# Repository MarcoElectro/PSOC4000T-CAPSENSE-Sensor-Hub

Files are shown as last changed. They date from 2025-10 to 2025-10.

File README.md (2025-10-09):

# PSOC4000T-CAPSENSE-Sensor-Hub
An simple way to use capacitive sensors in combination with Infineon's CAPSENSE technology.

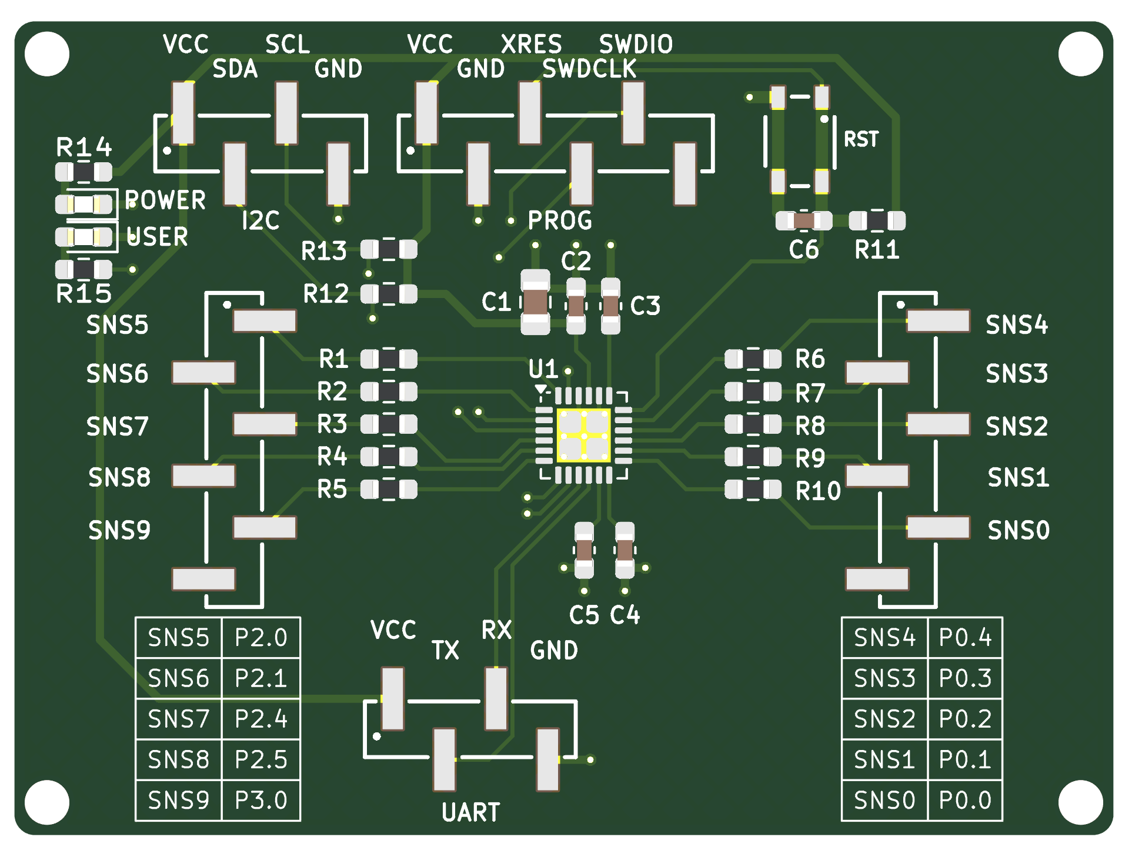
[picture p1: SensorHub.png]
Sensor Hub PCB


# Setup
After the PCB is soldered, the Rasperry Pi Pico needs to be connected as follows:
| Raspberry Pi Pico 2W Pin | Connection | Function |
|---|---|---|
| GPIO2 (Pin 4) | SDA (Sensor Hub) | I2C Data |
| GPIO3 (Pin 5) | SCL (Sensor Hub) | I2C Clock |
| GPIO28 (Pin 34) | VCC (Sensor Hub) | Power Supply (3.3V) |
| GND (Pin 3 or 38) | GND (Sensor Hub / BME280) | Ground |
| GPIO4 (Pin 6) | BME280 SDA | Environmental Sensor Data |
| GPIO5 (Pin 7) | BME280 SCL 

# PicoLogger
For obtaining the CAPSENSE data from the Sensor Hub, the PicoLogger can be controlled over an web interface. 
Connect to the AP of the PicoLogger and call following pages:

- Main page: http://192.168.4.1
- Status page:  http://192.168.4.1/status

On the status page, the current state is shown e.g IDLE or the running data collection.

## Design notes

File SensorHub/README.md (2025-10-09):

# KiCad Project for Sensor Hub PCB
The PCB conists of an PSOC4000T and a few additional components,
making the board a simple and cheap option to use Infineon`s CAPSENSE technology for capacitive sensors.

For programming an SWD Programmer is needed. 
I used the MiniProg4 (CY8CKIT-005-A).

Soldering the PSOC4000T is easy using solder paste and a heat plate or air soldering station.

Feel free to improve the layout and update it to your needs.

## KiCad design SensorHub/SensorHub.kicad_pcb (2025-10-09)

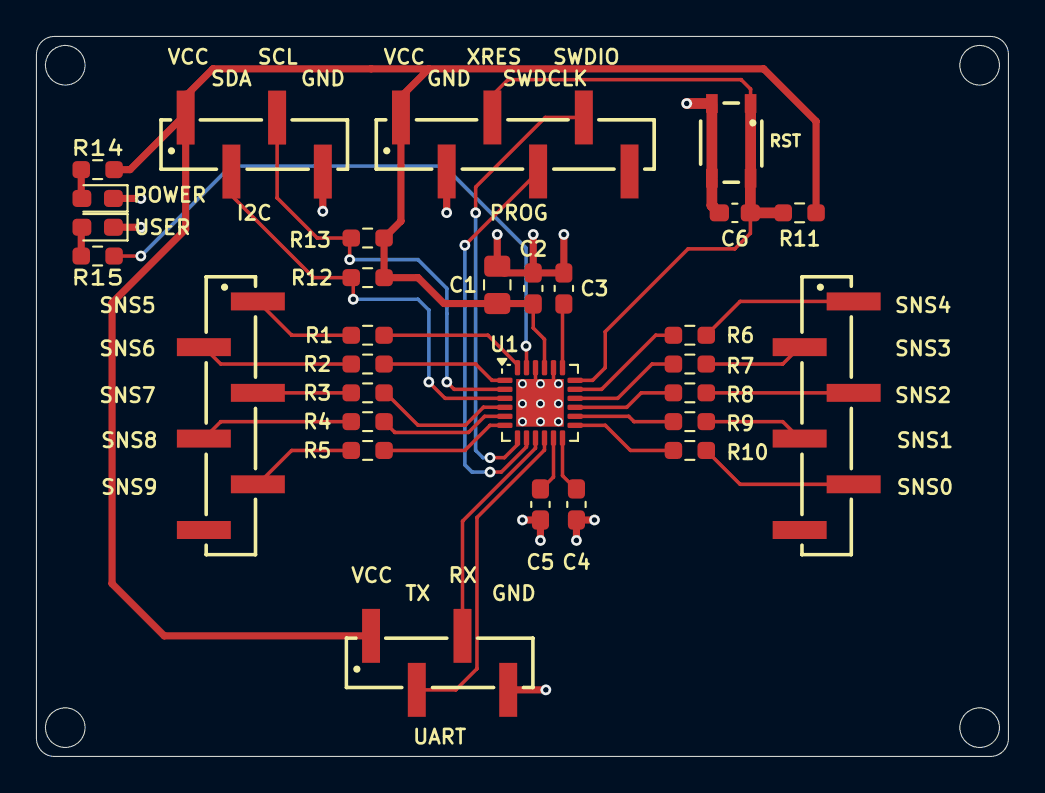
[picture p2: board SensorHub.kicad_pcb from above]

Board: 2 copper layers, 54.0 x 40.0 mm, 30 parts (0 on the bottom side), 35 nets.

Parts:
C1: 4.7 µF; C_0805_2012Metric_Pad1.18x1.45mm_HandSolder
C2: 0.1 µF; C_0603_1608Metric_Pad1.08x0.95mm_HandSolder
C3: 2.2 µF; C_0603_1608Metric_Pad1.08x0.95mm_HandSolder
C4, C5: 2.2 nF; C_0603_1608Metric_Pad1.08x0.95mm_HandSolder
C6: 0.1µF; C_0603_1608Metric_Pad1.08x0.95mm_HandSolder
I2C: I2C; 61000418321_5pins
J1: CS1; 61000618321_6pins
J2: CS2; 61000618321_6pins
POWER: POWER; LED_0603_1608Metric_Pad1.05x0.95mm_HandSolder
PROG: SWD; 61000618321_6pins
R1, R2, R3, R4, R5, R6, R7, R8, R9, R10, R14: 560R; R_0603_1608Metric_Pad0.98x0.95mm_HandSolder
R11, R12, R13, R15: 4k7; R_0603_1608Metric_Pad0.98x0.95mm_HandSolder
RST: RESET; 434133025816
U1: CY8C4046LQI-T452; QFN-24-1EP_4x4mm_P0.5mm_EP2.65x2.65mm
UART: UART; 61000418321_5pins
USER: USER; LED_0603_1608Metric_Pad1.05x0.95mm_HandSolder

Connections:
/SCL: I2C.3, R13.2, U1.2 (P2.2)
/SDA: I2C.2, R12.2, U1.3 (P2.3)
/SNS0: R10.1, U1.13 (P0.0)
/SNS1: R9.1, U1.14 (P0.1)
/SNS2: R8.1, U1.15 (P0.2)
/SNS3: R7.1, U1.16 (P0.3)
/SNS4: R6.1, U1.17 (EXTCLK_P0.4)
/SNS5: R1.1, U1.24 (P2.0)
/SNS6: R2.1, U1.1 (P2.1)
/SNS7: R3.1, U1.4 (P2.4)
/SNS8: R4.1, U1.5 (P2.5)
/SNS9: R5.1, U1.6 (P3.0)
/SWDCLK: PROG.4, U1.8 (SWDCLK_P3.3)
/SWDIO: PROG.5, U1.7 (SWDIO_P3.2)
/UART_RX: U1.9 (P4.0), UART.3
/UART_TX: U1.10 (P4.1), UART.2
/USER_LED: R15.1, U1.23 (P1.0)
/XRES: C6.1, PROG.3, R11.2, RST.1, RST.2, U1.18 (XRES)
GND: C1.2, C2.2, C3.2, C4.2, C5.2, C6.2, I2C.4, POWER.1 (K), PROG.2, RST.3, RST.4, U1.20 (VSSD), U1.22 (VSSA), U1.25 (VSS), UART.4, USER.1 (K)
unnamed: POWER.2 (A), R14.2
unnamed: R15.2, USER.2 (A)
unnamed: J1.1, R1.2
unnamed: J1.2, R2.2
unnamed: J1.3, R3.2
unnamed: J1.4, R4.2
unnamed: J1.5, R5.2
unnamed: J2.1, R6.2
unnamed: J2.2, R7.2
unnamed: J2.3, R8.2
unnamed: J2.4, R9.2
unnamed: J2.5, R10.2
unnamed: C5.1, U1.11 (CMOD1_P4.2)
unnamed: C4.1, U1.12 (CMOD2_P4.3)
unnamed: C3.1, U1.19 (VCCD)
VCC: C1.1, C2.1, I2C.1, PROG.1, R11.1, R12.1, R13.1, R14.1, U1.21 (VDDD), UART.1

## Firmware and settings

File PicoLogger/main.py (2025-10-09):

"""
PicoLogger - Web-based Environmental and CapSense Data Logger

This application transforms a Raspberry Pi Pico 2W into a standalone data logging system
that captures readings from both a BME280 environmental sensor and PSoC 4000T CapSense
touch sensors into an .csv file. It creates its own WiFi access point with a web interface for configuring
and controlling logging sessions.

Features:
- Self-hosted WiFi access point with browser-based control panel
- Logging of temperature, pressure, humidity, and capacitive touch data
- Configurable logging duration and sample rate
- Support for batch logging (multiple sequential sessions)
- CSV data output with timestamps for easy analysis
- LED status indication during logging sessions
- Error handling and recovery mechanisms

Hardware requirements:
- Raspberry Pi Pico 2W
- BME280 environmental sensor (I2C0: SCL=GPIO5, SDA=GPIO4)
- PSoC 4000T CapSense development board (I2C1: SCL=GPIO3, SDA=GPIO2)
- Power supply via USB or external source

Default WiFi credentials:
- SSID: PicoLogger
- Password: capsense

"""
import network
import socket
import time
import BME280
from machine import Pin, I2C
from capsense import CapsenseReader
import os
import uasyncio as asyncio

AP_NAME = "PicoLogger"
AP_PW = "capsense"

logging_status = {
    'active': False,
    'label': '',
    'start_time': 0,
    'duration': 0,
    'type': ''  # 'single' or 'batch'
}

led = Pin("LED", Pin.OUT)
led.off()
# Set VCC on pin 28 to power capsense board
VCC_PIN_1 = Pin(28, Pin.OUT)
VCC_PIN_1.on()
print("VCC pins 28 set high for power supply")

# Initialize hardware with basic error handling
try:
    i2c = I2C(0, scl=Pin(5), sda=Pin(4), freq=10000)    # I2C0 for BME280
    i2c1 = I2C(1, scl=Pin(3), sda=Pin(2), freq=40000)   # I2C1 for capsense
    capsense_reader = CapsenseReader(i2c_instance=i2c1)
    print("Using shared I2C instance")
    print("Capsense sensor found at 0x09")
except Exception as e:
    print(f"Sensor init error: {e}")
    capsense_reader = None



# Create logs directory
try:
    os.mkdir('logs')
except:
    print("Logs directory already exists or cannot be created")

# HTML content (keep your existing HTML)
html = """<!DOCTYPE html>
<html>
<head>
<meta charset="UTF-8">
<meta name="viewport" content="width=device-width,initial-scale=1">
<title>PicoLogger</title>
<style>
body{font-family:Arial,sans-serif;margin:10px;background:#f0f0f0}
.container{max-width:320px;margin:0 auto;background:white;padding:15px;border-radius:5px}
h1{text-align:center;margin:0 0 15px 0;font-size:18px;color:#333}
.group{margin-bottom:12px}
label{display:block;margin-bottom:3px;font-weight:bold;font-size:13px;color:#555}
input{width:100%;padding:6px;border:1px solid #ccc;border-radius:3px;box-sizing:border-box;font-size:14px}
input:focus{border-color:#4CAF50;outline:none}
.time{display:flex;gap:5px;align-items:center}
.time-part{flex:1}
.sep{font-weight:bold;font-size:16px}
button{width:100%;padding:10px;background:#4CAF50;color:white;border:none;border-radius:3px;font-size:15px;margin-top:8px}
button:disabled{background:#ccc}
.batch-btn{background:#2196F3;margin-top:5px}
.batch-btn:disabled{background:#ccc}
.status{margin-top:10px;padding:8px;border-radius:3px;text-align:center;display:none;font-size:13px}
.success{background:#d4edda;color:#155724}
.error{background:#f8d7da;color:#721c24}
.info{background:#d1ecf1;color:#0c5460}
.button-group{display:flex;gap:5px}
.button-group button{flex:1;margin-top:8px}
</style>
</head>
<body>
<div class="container">
<h1>PicoLogger</h1>
<form id="form">
<div class="group">
<label>Duration (sec)</label>
<input type="number" id="duration" min="1" max="100000" value="60" required>
</div>
<div class="group">
<label>Sample Rate (Hz)</label>
<input type="number" id="rate" min="0.01" max="10" step="0.01" value="0.1" required>
</div>
<div class="group">
<label>Time (24h)</label>
<div class="time">
<div class="time-part">
<input type="number" id="h" min="0" max="23" value="12" required>
</div>
<div class="sep">:</div>
<div class="time-part">
<input type="number" id="m" min="0" max="59" value="0" required>
</div>
</div>
</div>
<div class="group">
<label>Date</label>
<input type="date" id="date" required>
</div>
<div class="group">
<label>Label</label>
<input type="text" id="label" maxlength="20" required>
</div>
<div class="button-group">
<button type="submit" id="btn">Start Single Log</button>
<button type="button" id="batch-btn" class="batch-btn">Start Batch (4x)</button>
</div>
</form>
<div id="status" class="status"></div>
</div>
<script>
function setTime(){
var d=new Date();
document.getElementById('h').value=d.getHours();
document.getElementById('m').value=d.getMinutes();
var year = d.getFullYear();
var month = String(d.getMonth() + 1).padStart(2, '0');
var day = String(d.getDate()).padStart(2, '0');
document.getElementById('date').value = year + '-' + month + '-' + day;
}
setTime();

function disableButtons(disabled) {
    document.getElementById('btn').disabled = disabled;
    document.getElementById('batch-btn').disabled = disabled;
}

function showStatus(message, type) {
    var status = document.getElementById('status');
    status.className = 'status ' + type;
    status.textContent = message;
    status.style.display = 'block';
}

function hideStatus() {
    document.getElementById('status').style.display = 'none';
}

function startLogging(endpoint, buttonText, successMessage) {
    var h = document.getElementById('h').value;
    var m = document.getElementById('m').value;
    var date = document.getElementById('date').value;
    if (h < 10) h = '0' + h;
    if (m < 10) m = '0' + m;

    disableButtons(true);
    document.getElementById('btn').textContent = buttonText;
    document.getElementById('batch-btn').textContent = buttonText;
    hideStatus();

    var params = "duration=" + encodeURIComponent(document.getElementById('duration').value) +
                 "&sample_rate=" + encodeURIComponent(document.getElementById('rate').value) +
                 "&date=" + encodeURIComponent(date) +
                 "&clock_time=" + encodeURIComponent(h + ":" + m) +
                 "&label=" + encodeURIComponent(document.getElementById('label').value);

    var xhr = new XMLHttpRequest();
    xhr.open('POST', endpoint, true);
    xhr.setRequestHeader('Content-Type', 'application/x-www-form-urlencoded');
    xhr.onload = function() {
        if (xhr.status === 200) {
            showStatus(successMessage, 'success');
            document.getElementById('label').value = '';
        } else {
            showStatus('Failed', 'error');
        }
        disableButtons(false);
        document.getElementById('btn').textContent = 'Start Single Log';
        document.getElementById('batch-btn').textContent = 'Start Batch (4x)';
        setTimeout(hideStatus, 5000);
    };
    xhr.onerror = function() {
        showStatus('Connection Error', 'error');
        disableButtons(false);
        document.getElementById('btn').textContent = 'Start Single Log';
        document.getElementById('batch-btn').textContent = 'Start Batch (4x)';
        setTimeout(hideStatus, 5000);
    };
    xhr.send(params);
}

// Single logging
document.getElementById('form').onsubmit = function(e) {
    e.preventDefault();
    startLogging('/start_logging', 'Logging...', 'Single log finished!');
};

// Batch logging
document.getElementById('batch-btn').onclick = function(e) {
    e.preventDefault();
    if (document.getElementById('form').checkValidity()) {
        startLogging('/start_batch', 'Batch logging...', 'Batch complete! (4 files created)');
    } else {
        showStatus('Please fill all fields', 'error');
        setTimeout(hideStatus, 3000);
    }
};
</script>
</body>
</html>
"""

# Configure the Pico W as an access point
ap = network.WLAN(network.AP_IF)
ap.active(True)
ap.config(essid=AP_NAME, password=AP_PW) 
print("Access point created. SSID:", AP_NAME, ", Password:", AP_PW)

while not ap.active():
    time.sleep(1)

print("Access point is active. IP:", ap.ifconfig()[0])

# Start HTTP server
addr = socket.getaddrinfo("0.0.0.0", 80)[0][-1]
s = socket.socket()
s.setsockopt(socket.SOL_SOCKET, socket.SO_REUSEADDR, 1)
s.bind(addr)
s.listen(1)
print("Listening on", addr)

def getBMEdata():
    """Get BME280 data with simple error handling"""
    try:
        bme = BME280.BME280(i2c=i2c)
        return bme.temperature, bme.humidity, bme.pressure
    except Exception as e:
        print(f"BME280 error: {e}")
        return "ERROR", "ERROR", "ERROR"

def get_capsense_data():
    """Get capsense data with error handling"""
    if capsense_reader is None:
        return "NO_SENSOR," * 11 + "NO_SENSOR"  # 12 values
    
    try:
        capsense_csv = capsense_reader.get_csv_string()
        if capsense_csv:
            return capsense_csv
        else:
            return "EMPTY," * 11 + "EMPTY"
    except Exception as e:
        print(f"Capsense error: {e}")
        return "ERROR," * 11 + "ERROR"

async def record_batch_data(duration, sample_rate, label, clock_time, start_date):
    """Record 4 batches of data asynchronously."""
    global logging_status

    logging_status['active'] = True
    logging_status['label'] = label
    logging_status['start_time'] = time.time()
    logging_status['duration'] = duration * 4 + 6  # 4 logs + gaps
    logging_status['type'] = 'batch'

    print(f"Starting batch recording: {label}")
    print(f"Will create 4 files: {label}_1.csv to {label}_4.csv")

    for i in range(1, 5):
        batch_label = f"{label}_{i}"
        print(f"\n=== Batch {i}/4: {batch_label} ===")

        batch_start_seconds = 0
        if i > 1:
            batch_start_seconds = (i - 1) * (duration + 2)

        hours, minutes = map(int, clock_time.split(':'))
        start_seconds = hours * 3600 + minutes * 60

        new_hours = int((start_seconds // 3600) % 24)
        new_minutes = int((start_seconds % 3600) // 60)
        batch_clock_time = f"{new_hours:02d}:{new_minutes:02d}"

        print(f"Batch {i} start time: {batch_clock_time}")

        await execute_logging(duration, sample_rate, batch_label, batch_clock_time, start_date)

        if i < 4:
            print(f"Waiting 2 seconds before batch {i+1}...")
            await asyncio.sleep(2)

    logging_status['active'] = False
    logging_status['label'] = ''
    print("Batch recording finished.")


def read_http_request(cl):
    """Read and parse HTTP request"""
    try:
        cl.settimeout(5.0)  # Increased timeout
        request = cl.recv(4096).decode('utf-8')
        print(f"Raw request received: {len(request)} bytes")
        
        if '\r\n\r\n' in request:
            headers, body = request.split('\r\n\r\n', 1)
        else:
            headers = request
            body = ""
        
        # For POST requests, check if we need to read more data
        if "POST" in headers and "Content-Length:" in headers:
            try:
                # Extract content length from headers
                lines = headers.split('\r\n')
                content_length = 0
                for line in lines:
                    if line.lower().startswith('content-length:'):
                        content_length = int(line.split(':')[1].strip())
                        break
                
                print(f"Content-Length: {content_length}, Body length: {len(body)}")
                
                # If we haven't received all the body data, read more
                while len(body) < content_length:
                    remaining = content_length - len(body)
                    additional_data = cl.recv(min(remaining, 1024)).decode('utf-8')
                    if not additional_data:
                        break
                    body += additional_data
                    print(f"Read additional {len(additional_data)} bytes, total body: {len(body)}")
                    
            except Exception as e:
                print(f"Error reading POST body: {e}")
        
        return headers, body
    except Exception as e:
        print(f"Request read error: {e}")
        return "", ""

def parse_form_data(body):
    """Parse URL-encoded form data"""
    data = {}
    if body:
        pairs = body.split('&')
        for pair in pairs:
            if '=' in pair:
                key, value = pair.split('=', 1)
                # Simple URL decode for common characters
                value = value.replace('%20', ' ').replace('%3A', ':').replace('%2D', '-')
                data[key] = value
    print(f"Form data parsed: {data}")  # Debugging print
    return data

async def execute_logging(duration, sample_rate, label, clock_time, start_date):
    """Execute single logging session asynchronously."""
    global logging_status

    # Set logging status to active
    logging_status['active'] = True
    logging_status['label'] = label
    logging_status['start_time'] = time.time()
    logging_status['duration'] = duration
    logging_status['type'] = 'single'

    print(f"Starting logging: {label}")
    print(f"Duration: {duration}s, Rate: {sample_rate}Hz")
    print(f"Start date: {start_date}, Clock time: {clock_time}")

    led.on()

    try:
        # Parse the start date and time
        year, month, day = map(int, start_date.split('-'))
        hours, minutes = map(int, clock_time.split(':'))
        start_seconds = hours * 3600 + minutes * 60

        interval = 1.0 / sample_rate
        total_samples = int(duration * sample_rate)

        print(f"Sample interval: {interval:.2f} seconds")
        print(f"Total samples: {total_samples}")

        # Create CSV header
        if capsense_reader:
            capsense_header = capsense_reader.get_csv_header()
        else:
            capsense_header = "capsense_unavailable"

        csv_header = f"Time,BME280_temperature,BME280_humidity,BME280_pressure,{capsense_header}\n"

        # Write header to file with error handling
        try:
            with open(f"logs/{label}.csv", "w") as f:
                f.write(csv_header)
            print(f"Created CSV file: logs/{label}.csv")
        except Exception as e:
            print(f"Error creating file: {e}")
            logging_status['active'] = False
            return

        successful_samples = 0
        failed_samples = 0
        consecutive_errors = 0
        MAX_CONSECUTIVE_ERRORS = 5;

        # Open file once and keep it open for better performance
        try:
            log_file = open(f"logs/{label}.csv", "a")
        except Exception as e:
            print(f"Error opening file: {e}")
            logging_status['active'] = False
            return

        for i in range(total_samples):
            try:
                if consecutive_errors >= MAX_CONSECUTIVE_ERRORS:
                    print(f"Stopping: {MAX_CONSECUTIVE_ERRORS} consecutive errors")
                    break

                # Only print every 10th sample to reduce overhead
                if i % 10 == 0 or i < 3:
                    print(f"Logging sample {i+1}/{total_samples}...")

                # Get sensor data
                temperature, humidity, pressure = getBMEdata()
                capsense_csv = get_capsense_data()

                # Calculate current datetime based on start parameters and sample number
                current_total_seconds = start_seconds + (i * interval)
                current_day_offset = int(current_total_seconds // 86400)
                current_seconds_in_day = current_total_seconds % 86400

                current_hours = int(current_seconds_in_day // 3600)
                current_minutes = int((current_seconds_in_day % 3600) // 60)
                current_seconds = int(current_seconds_in_day % 60)
                current_milliseconds = int((current_seconds_in_day % 1) * 1000)

                if current_day_offset == 0:
                    current_date = f"{year:04d}-{month:02d}-{day:02d}"
                else:
                    # Handle day rollover (simplified)
                    new_day = day + current_day_offset
                    new_month = month
                    new_year = year
                    
                    while new_day > 30:  # Simplified - you might want more accurate month handling
                        new_day -= 30
                        new_month += 1
                        if new_month > 12:
                            new_month = 1
                            new_year += 1
                    
                    current_date = f"{new_year:04d}-{new_month:02d}-{new_day:02d}"

                datetime_str = f"{current_date} {current_hours:02d}:{current_minutes:02d}:{current_seconds:02d}.{current_milliseconds:03d}"

                log_entry = f"{datetime_str},{temperature},{humidity},{pressure},{capsense_csv}\n"

                try:
                    log_file.write(log_entry)
                    log_file.flush();
                    successful_samples += 1
                    consecutive_errors = 0
                except Exception as e:
                    print(f"File write error at sample {i+1}: {e}")
                    failed_samples += 1
                    consecutive_errors += 1

            except Exception as e:
                print(f"Sample {i+1} error: {e}")
                failed_samples += 1
                consecutive_errors += 1

            # Wait for the next sample (remove the verbose print)
            await asyncio.sleep(interval)

        # Close the file
        log_file.close()

        print(f"Logging complete: {successful_samples}/{total_samples} samples logged successfully.")
        logging_status['active'] = False
        logging_status['label'] = ''

    except Exception as e:
        print(f"Critical logging error: {e}")
        logging_status['active'] = False
    finally:
        led.off()
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

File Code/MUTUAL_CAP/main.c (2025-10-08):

/*******************************************************************************
* File Name:   main.c
*
* Description: Source code for the mutual capacitance sensor setup
* Changes on the sensors need to be done using CAPSENSE Configurator
* and then re-program the board, so that the sensor context is updated
*
*
*
*******************************************************************************
* Copyright 2024, Cypress Semiconductor Corporation (an Infineon company) or
* an affiliate of Cypress Semiconductor Corporation.  All rights reserved.
*
* This software, including source code, documentation and related
* materials ("Software") is owned by Cypress Semiconductor Corporation
* or one of its affiliates ("Cypress") and is protected by and subject to
* worldwide patent protection (United States and foreign),
* United States copyright laws and international treaty provisions.
* Therefore, you may use this Software only as provided in the license
* agreement accompanying the software package from which you
* obtained this Software ("EULA").
* If no EULA applies, Cypress hereby grants you a personal, non-exclusive,
* non-transferable license to copy, modify, and compile the Software
* source code solely for use in connection with Cypress's
* integrated circuit products.  Any reproduction, modification, translation,
* compilation, or representation of this Software except as specified
* above is prohibited without the express written permission of Cypress.
*
* Disclaimer: THIS SOFTWARE IS PROVIDED AS-IS, WITH NO WARRANTY OF ANY KIND,
* EXPRESS OR IMPLIED, INCLUDING, BUT NOT LIMITED TO, NONINFRINGEMENT, IMPLIED
* WARRANTIES OF MERCHANTABILITY AND FITNESS FOR A PARTICULAR PURPOSE. Cypress
* reserves the right to make changes to the Software without notice. Cypress does
* not assume any liability arising out of the application or use of the
* Software or any product or circuit described in the Software. Cypress does
* not authorize its products for use in any products where a malfunction or
* failure of the Cypress product may reasonably be expected to result in
* significant property damage, injury or death ("High Risk Product"). By
* including Cypress's product in a High Risk Product, the manufacturer
* of such system or application assumes all risk of such use and in doing
* so agrees to indemnify Cypress against all liability.
*******************************************************************************/


/*******************************************************************************
* Header Files
*******************************************************************************/
#include "cy_capsense_structure.h"
#include "cy_pdl.h"
#include "cybsp.h"
#include "cycfg.h"
#include "cycfg_capsense.h"
#include <stdio.h>

//#include "cy_retarget_io.h"
// Update NUM_OF_SENSORS to match your actual sensor count (can also be checked with cy_capsense_tuner.sensorContext size)
#define NUM_OF_SENSORS (sizeof(cy_capsense_tuner.sensorContext) / sizeof(cy_capsense_tuner.sensorContext[0]))

// Struct for storing the capsense values for sending it over I2C
struct
{
	uint16_t rawcount[NUM_OF_SENSORS];
	uint16_t diffcount[NUM_OF_SENSORS];
	uint16_t baseline[NUM_OF_SENSORS];
}capsense_data;







cy_stc_scb_ezi2c_context_t ezi2c_context;
/*******************************************************************************
* Function Name: capsense_msc0_isr
********************************************************************************
* Summary:
*  Wrapper function for handling interrupts from CAPSENSE MSC0 block.
*
*******************************************************************************/
static void capsense_msc0_isr(void)
{
    Cy_CapSense_InterruptHandler(CY_MSCLP0_HW, &cy_capsense_context);
}

/*******************************************************************************
* Function Name: ezi2c_isr
********************************************************************************
* Summary:
* Wrapper function for handling interrupts from EZI2C block.
*
*******************************************************************************/
static void ezi2c_isr(void)
{
    Cy_SCB_EZI2C_Interrupt(EZI2C_HW, &ezi2c_context);
}



int main(void)
{
    cy_rslt_t result;
    uint32_t cnt = 0;
	char uart_buffer[200];
    /* Initialize the device and board peripherals */
    result = cybsp_init() ;
    if (result != CY_RSLT_SUCCESS)
    {

    }

	/* Enable global interrupts */
	__enable_irq();

    cy_capsense_status_t status = CY_CAPSENSE_STATUS_SUCCESS;

    Cy_SCB_UART_Init(UART_HW, &UART_config, NULL);
    Cy_SCB_UART_Enable(UART_HW);
//    cy_retarget_io_init(UART_HW);
	
//    printf("Started");


	/* CAPSENSE interrupt configuration MSC 0 */
	const cy_stc_sysint_t capsense_msc0_interrupt_config =
	{
		.intrSrc = CY_MSCLP0_LP_IRQ,
		.intrPriority = 0x03,
	};

	/* Capture the MSC HW block and initialize it to the default state. */
	status = Cy_CapSense_Init(&cy_capsense_context);

	if (CY_CAPSENSE_STATUS_SUCCESS == status)
	{
		/* Initialize CAPSENSE interrupt for MSC 0 */
		Cy_SysInt_Init(&capsense_msc0_interrupt_config, capsense_msc0_isr);
		NVIC_ClearPendingIRQ(capsense_msc0_interrupt_config.intrSrc);
		NVIC_EnableIRQ(capsense_msc0_interrupt_config.intrSrc);

		/* Initialize the CAPSENSE firmware modules. */
		status = Cy_CapSense_Enable(&cy_capsense_context);
	}


	/* EZI2C interrupt configuration structure */
	const cy_stc_sysint_t ezi2c_intr_config =
	{
		.intrSrc = EZI2C_IRQ,
		.intrPriority = 0x03,
	};

	/* Initialize the EzI2C firmware module */
	status = Cy_SCB_EZI2C_Init(EZI2C_HW, &EZI2C_config, &ezi2c_context);

	if(status != CY_SCB_EZI2C_SUCCESS)
	{
		while(1);
	}

	Cy_SysInt_Init(&ezi2c_intr_config, ezi2c_isr);
	NVIC_EnableIRQ(ezi2c_intr_config.intrSrc);

	/* Set the CAPSENSE data structure as the I2C buffer to be exposed to the
	 * master on primary slave address interface. Any I2C host tools such as
	 * the Tuner or the Bridge Control Panel can read this buffer but you can
	 * connect only one tool at a time.
	 * Address of this Buffer is 0x08
	 */
	Cy_SCB_EZI2C_SetBuffer1(EZI2C_HW, (uint8_t *)&cy_capsense_tuner,
							sizeof(cy_capsense_tuner), sizeof(cy_capsense_tuner),
							&ezi2c_context);
    
    /* Set up the secondary buffer for our custom data structure
     * so it can be read by another MCU via I2C
     * Address of this Buffer is 0x09
     * Can be accessed with a normal I2C read command
     */
    Cy_SCB_EZI2C_SetBuffer2(EZI2C_HW, (uint8_t *)&capsense_data,
                            sizeof(capsense_data), sizeof(capsense_data),
                            &ezi2c_context);

    // Enable the I2C
	Cy_SCB_EZI2C_Enable(EZI2C_HW);



    /* Start the first scan */
	Cy_CapSense_ScanAllSlots(&cy_capsense_context);

	for (;;)
	{
		if(CY_CAPSENSE_NOT_BUSY == Cy_CapSense_IsBusy(&cy_capsense_context))
		{
			/* Process all widgets */
			Cy_CapSense_ProcessAllWidgets(&cy_capsense_context);
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
